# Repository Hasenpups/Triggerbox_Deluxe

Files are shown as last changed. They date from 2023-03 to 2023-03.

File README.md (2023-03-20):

Shield: [][cc-by-nc-sa]

This work is licensed under a
[Creative Commons Attribution-NonCommercial-ShareAlike 4.0 International License][cc-by-nc-sa].

[][cc-by-nc-sa]

[cc-by-nc-sa]: http://creativecommons.org/licenses/by-nc-sa/4.0/
[cc-by-nc-sa-image]: https://licensebuttons.net/l/by-nc-sa/4.0/88x31.png
[cc-by-nc-sa-shield]: https://img.shields.io/badge/License-CC%20BY--NC--SA%204.0-lightgrey.svg

## Donations / Spenden
If somebody wants to support me for upcoming projects :)  
- PayPal:  
- Amazon Giftcard: https://www.amazon.de/Amazon-Gutschein-per-E-Mail-Amazon/dp/B0054PDOV8 - stefan.riese@me.com

# Triggerbox Deluxe

It's a trigger device for multiple devices and input counter.
- Raspberry Pi Pico
- 24V power input
- 8 x optocoupler input
- 8 x high side switch 24V 500mA output
- optional Wifi interface instead of USB connection (ESP32C3)



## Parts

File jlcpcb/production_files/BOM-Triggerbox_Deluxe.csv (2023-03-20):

Comment | Designator | Footprint | LCSC
AO3401A | Q1,Q10,Q11,Q12,Q2,Q3,Q4,Q9 | SOT-23 | C15127
47µF | C2 | C_0805_2012Metric | C16780
10µF | C1 | C_0603_1608Metric | C19702
2N3904 | Q13,Q14,Q15,Q16,Q5,Q6,Q7,Q8 | SOT-23 | C20526
1K | R10,R11,R12,R25,R26,R27,R28,R29,R30,R31,R32,R5,R6,R7,R8,R9 | R_0603_1608Metric | C21190
220 | R65 | R_0603_1608Metric | C22962
3K3 | R13,R15,R17,R19,R33,R35,R37,R39,R41,R44,R47,R50,R53,R56,R59,R62 | R_0603_1608Metric | C22978
4.7K | R42,R43,R45,R46,R48,R49,R51,R52,R54,R55,R57,R58,R60,R61,R63,R64,R67 | R_0603_1608Metric | C23162
560 | R66 | R_0603_1608Metric | C23204
10K | R1,R14,R16,R18,R2,R20,R21,R22,R23,R24,R3,R34,R36,R38,R4,R40 | R_0603_1608Metric | C25804
EL3H7-G | U10,U11,U4,U5,U6,U7,U8,U9 | SOIC127P700X200-4N | C32565
100n | C10,C11,C4,C5,C6,C7,C8,C9 | C_0805_2012Metric_Pad1.18x1.45mm_HandSolder | C49678
AMS1117-3.3 | U1 | SOT-223-3_TabPin2 | C6186
LED | D1,D10,D11,D12,D13,D14,D15,D16,D17,D18,D19,D2,D3,D4,D5,D6,D7,D8,D9 | LED_0805_2012Metric | C84256
Conn_02x08_Odd_Even | J4 | PinHeader_2x08_P2.54mm_Vertical
Conn_02x03_Odd_Even | J3 | PinHeader_2x03_P2.54mm_Vertical
MountingHole | H1 | MountingHole_3.2mm_M3_DIN965_Pad
78TV | IC1 | TO-220-3_Horizontal_TabUp
MountingHole | H4 | MountingHole_3.2mm_M3_DIN965_Pad
MountingHole | H3 | MountingHole_3.2mm_M3_DIN965_Pad
C-EUC1206 | C3 | C_1206_3216Metric
Screw_Terminal_01x10 | J1 | TerminalBlock_Phoenix_MKDS-1,5-10-5.08_1x10_P5.08mm_Horizontal
Screw_Terminal_01x10 | J2 | TerminalBlock_Phoenix_MKDS-1,5-10-5.08_1x10_P5.08mm_Horizontal
MountingHole | H2 | MountingHole_3.2mm_M3_DIN965_Pad
C | C12 | C_1206_3216Metric_Pad1.33x1.80mm_HandSolder
ESP-01v090 | U3 | ESP-01
Conn_02x08_Odd_Even | J5 | PinHeader_2x08_P2.54mm_Vertical
Pico | U2 | RPi_Pico_SMD_TH
Jumper_2_Open | JP3 | PinHeader_1x02_P2.54mm_Vertical
Jumper_2_Open | JP2 | PinHeader_1x02_P2.54mm_Vertical
Jumper_2_Open | JP1 | PinHeader_1x02_P2.54mm_Vertical

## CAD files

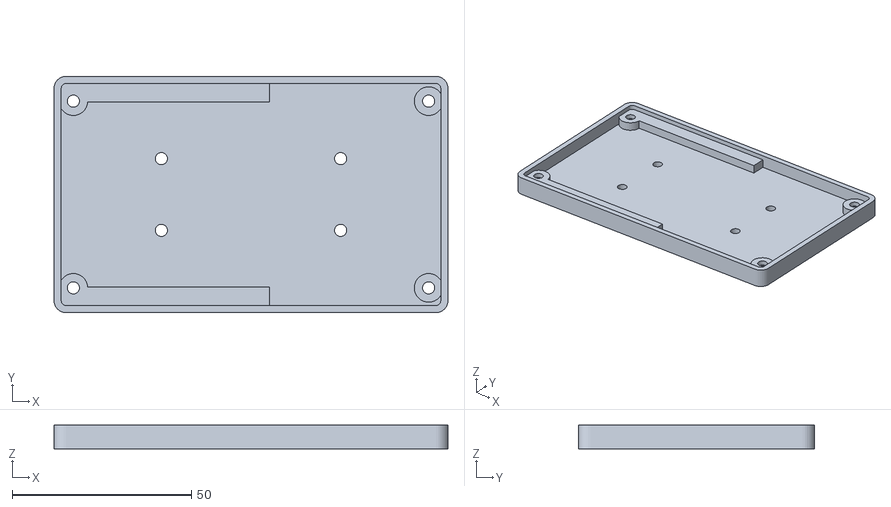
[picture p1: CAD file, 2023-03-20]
Housing/Triggerbox_Deluxe_Base.stl
109.9 x 65.9 x 6.60

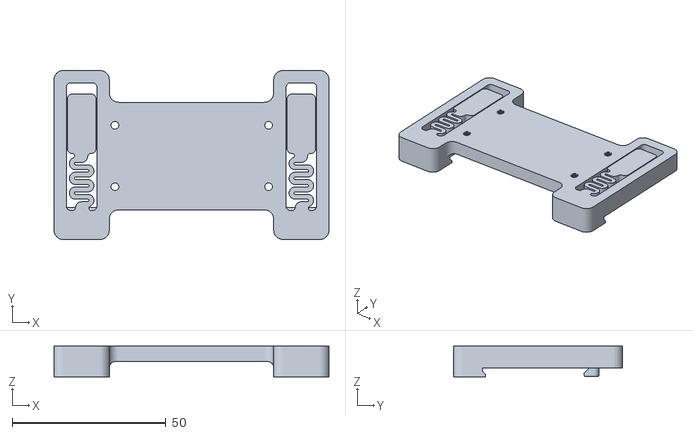
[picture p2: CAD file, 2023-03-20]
Housing/Triggerbox_Deluxe_Rail_Mount.stl
89.5 x 55.0 x 10.0

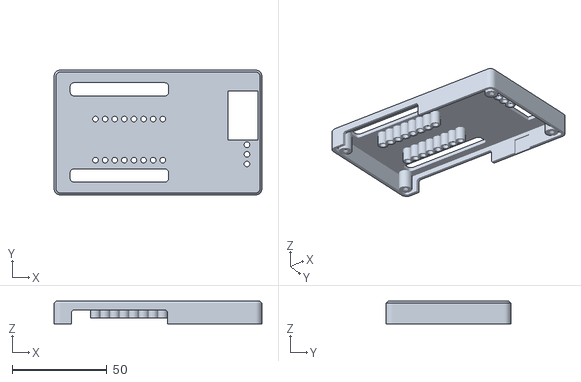
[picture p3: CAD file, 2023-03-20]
Housing/Triggerbox_Deluxe_Top.stl
109.9 x 65.9 x 12.0

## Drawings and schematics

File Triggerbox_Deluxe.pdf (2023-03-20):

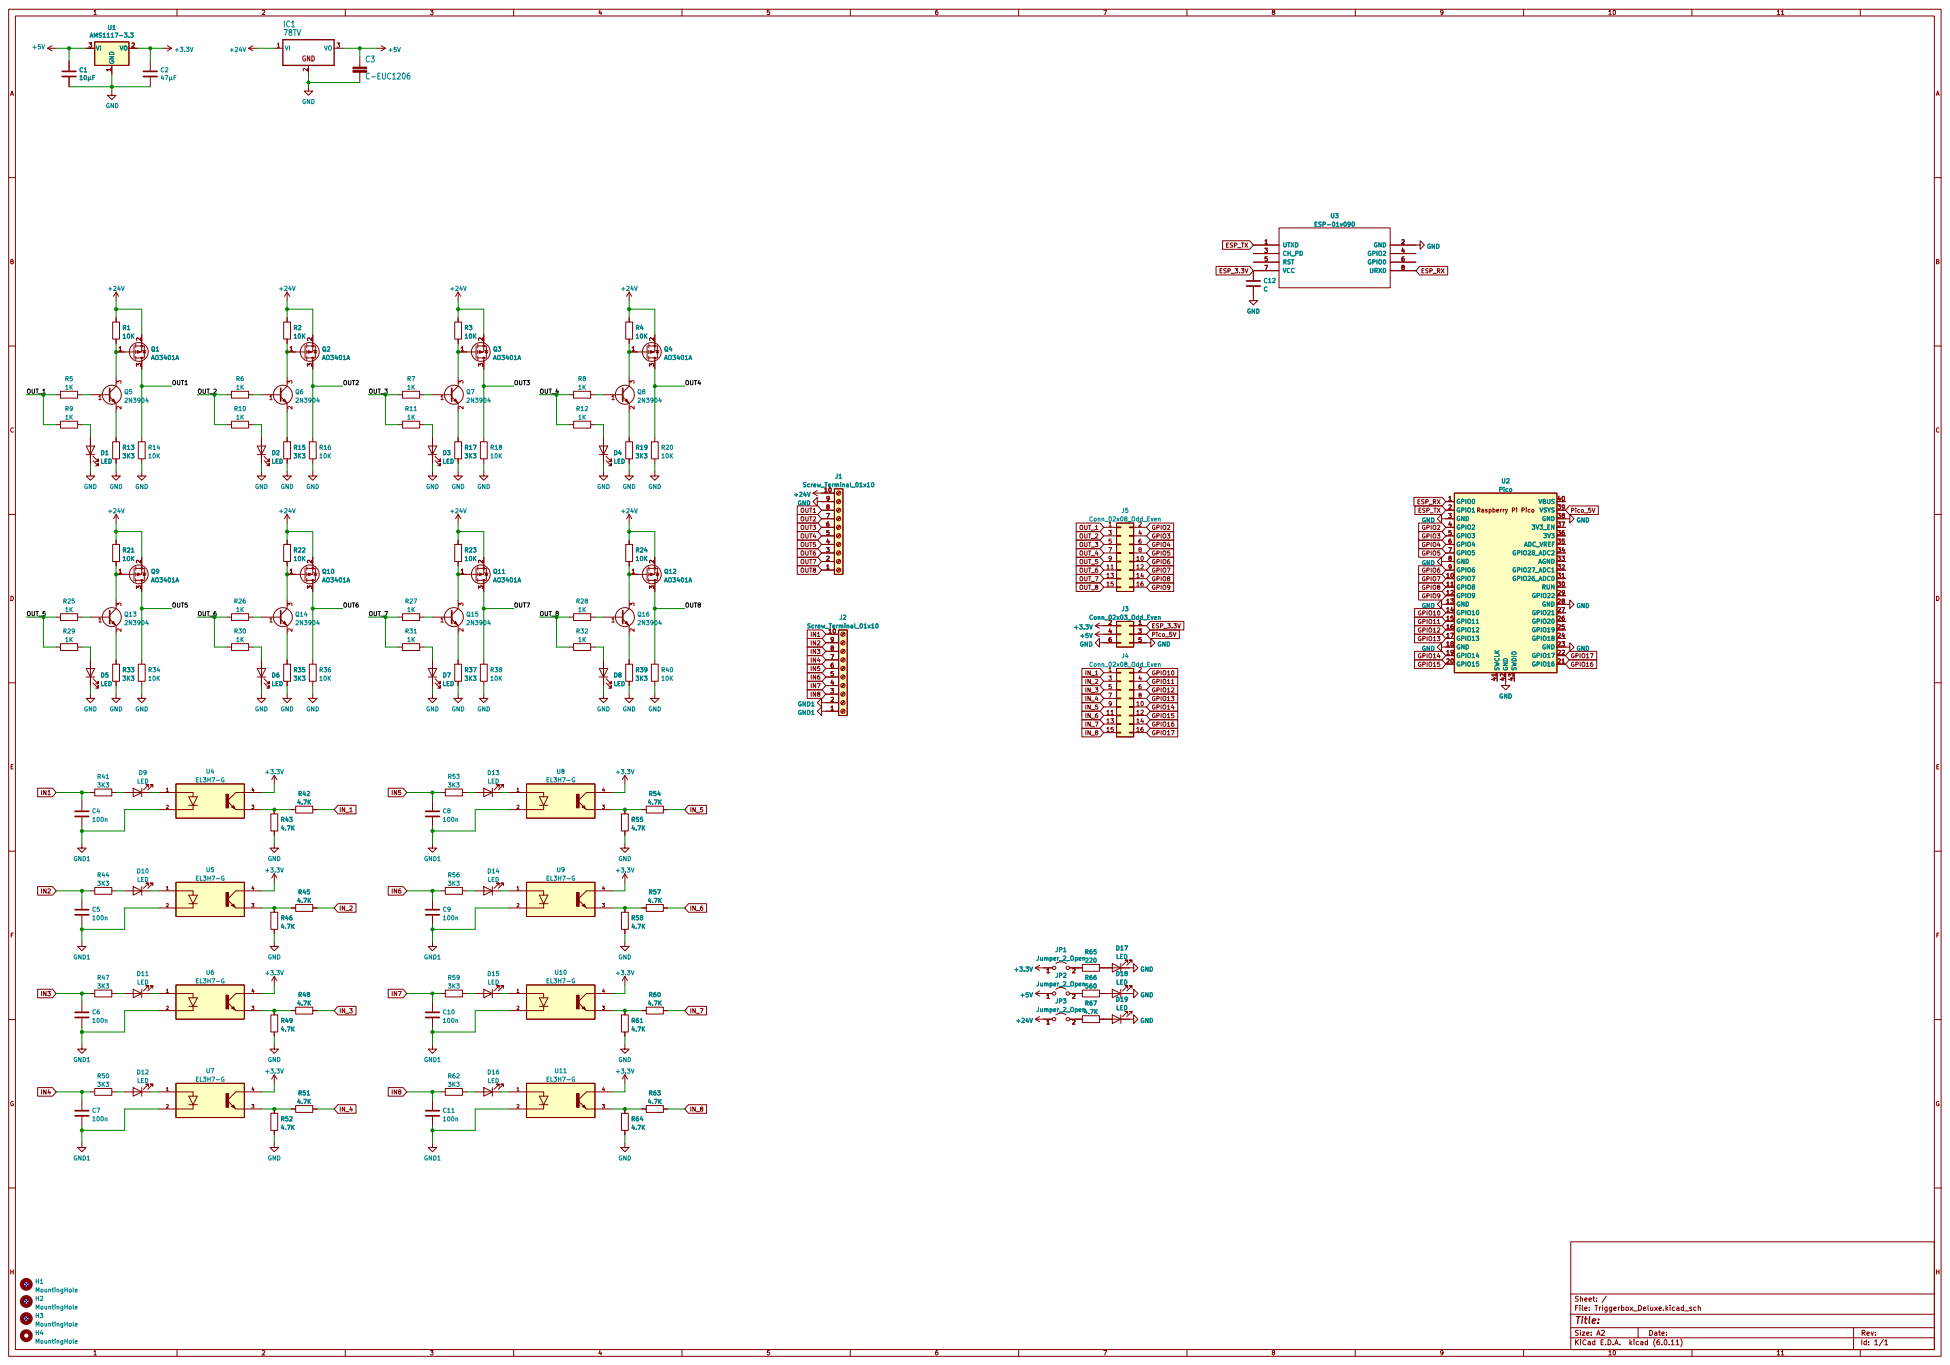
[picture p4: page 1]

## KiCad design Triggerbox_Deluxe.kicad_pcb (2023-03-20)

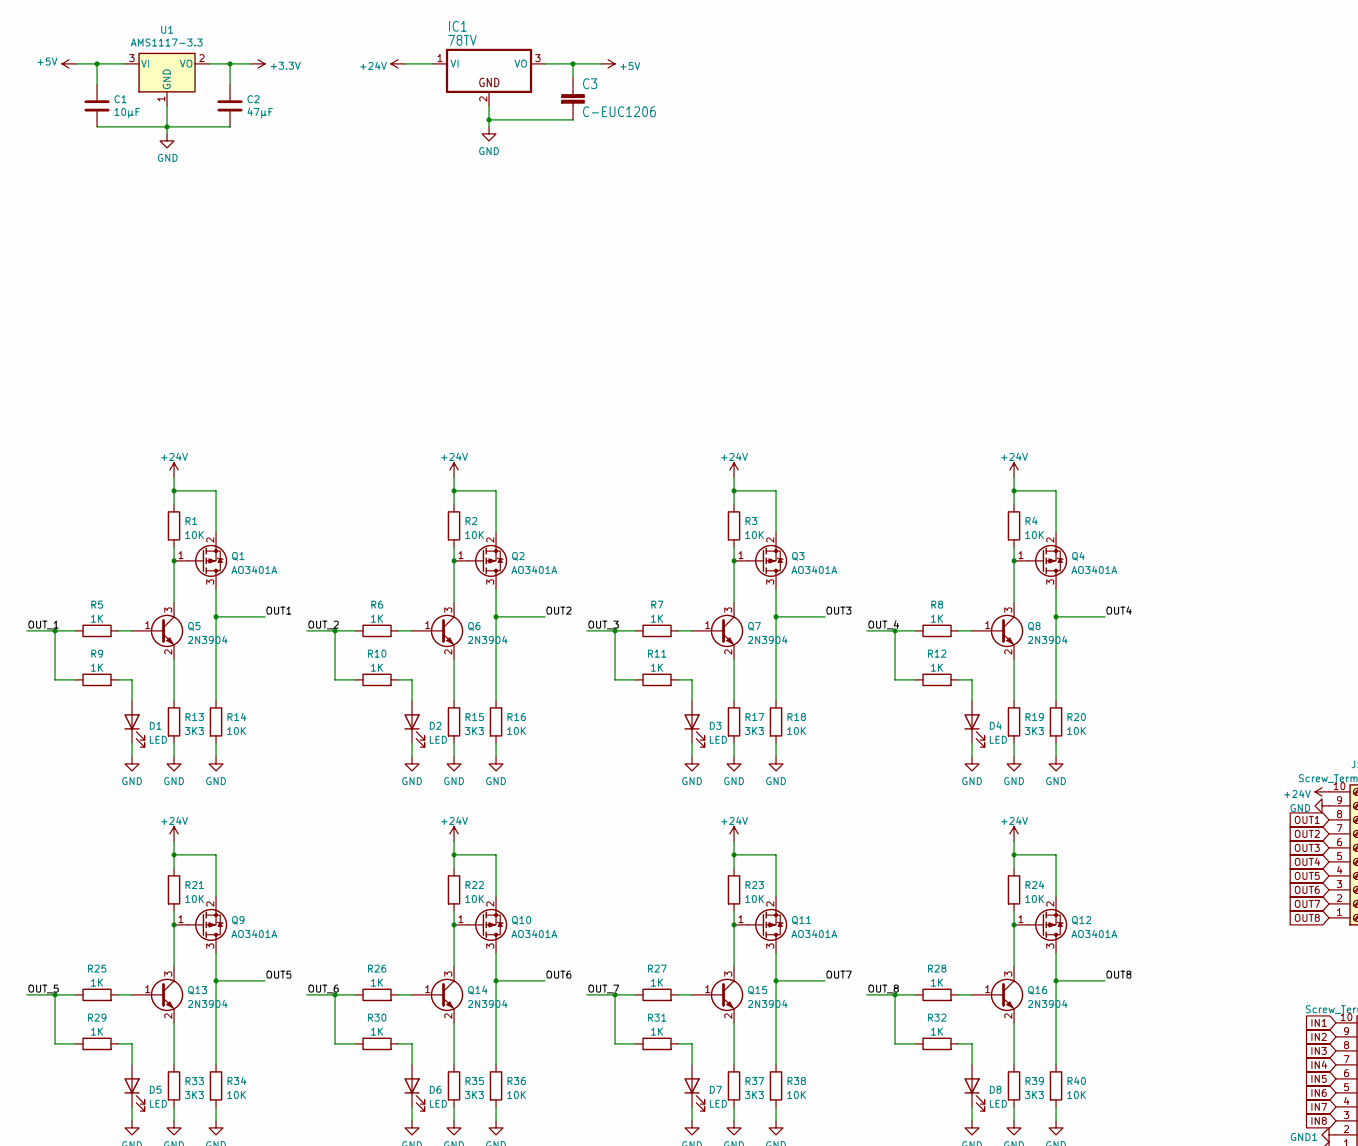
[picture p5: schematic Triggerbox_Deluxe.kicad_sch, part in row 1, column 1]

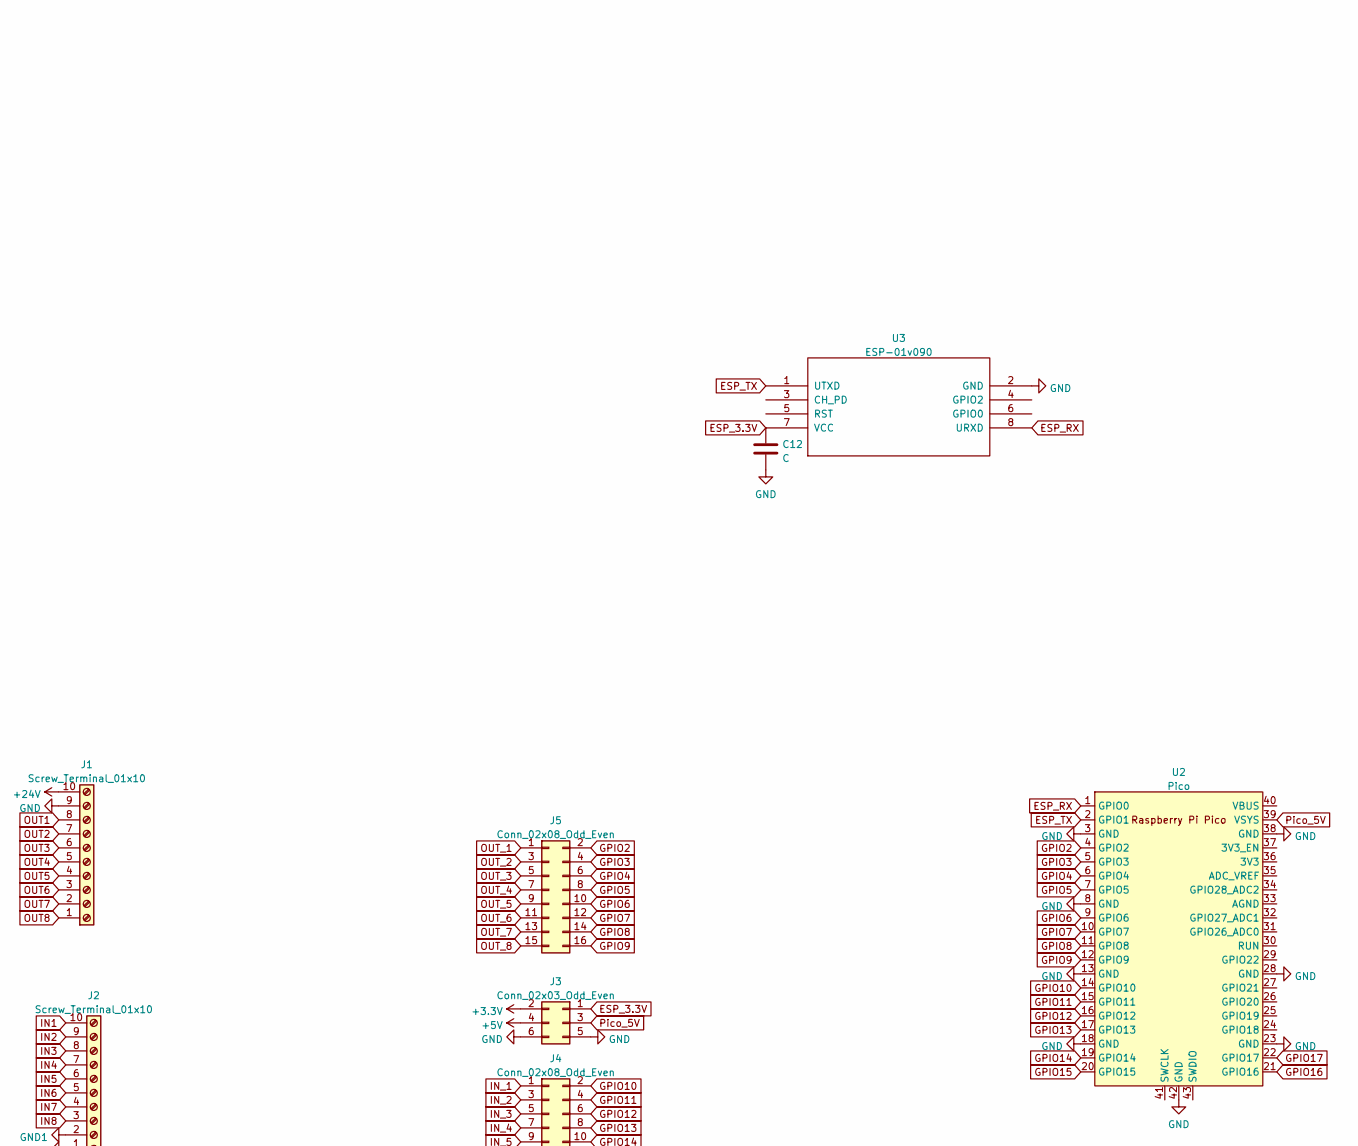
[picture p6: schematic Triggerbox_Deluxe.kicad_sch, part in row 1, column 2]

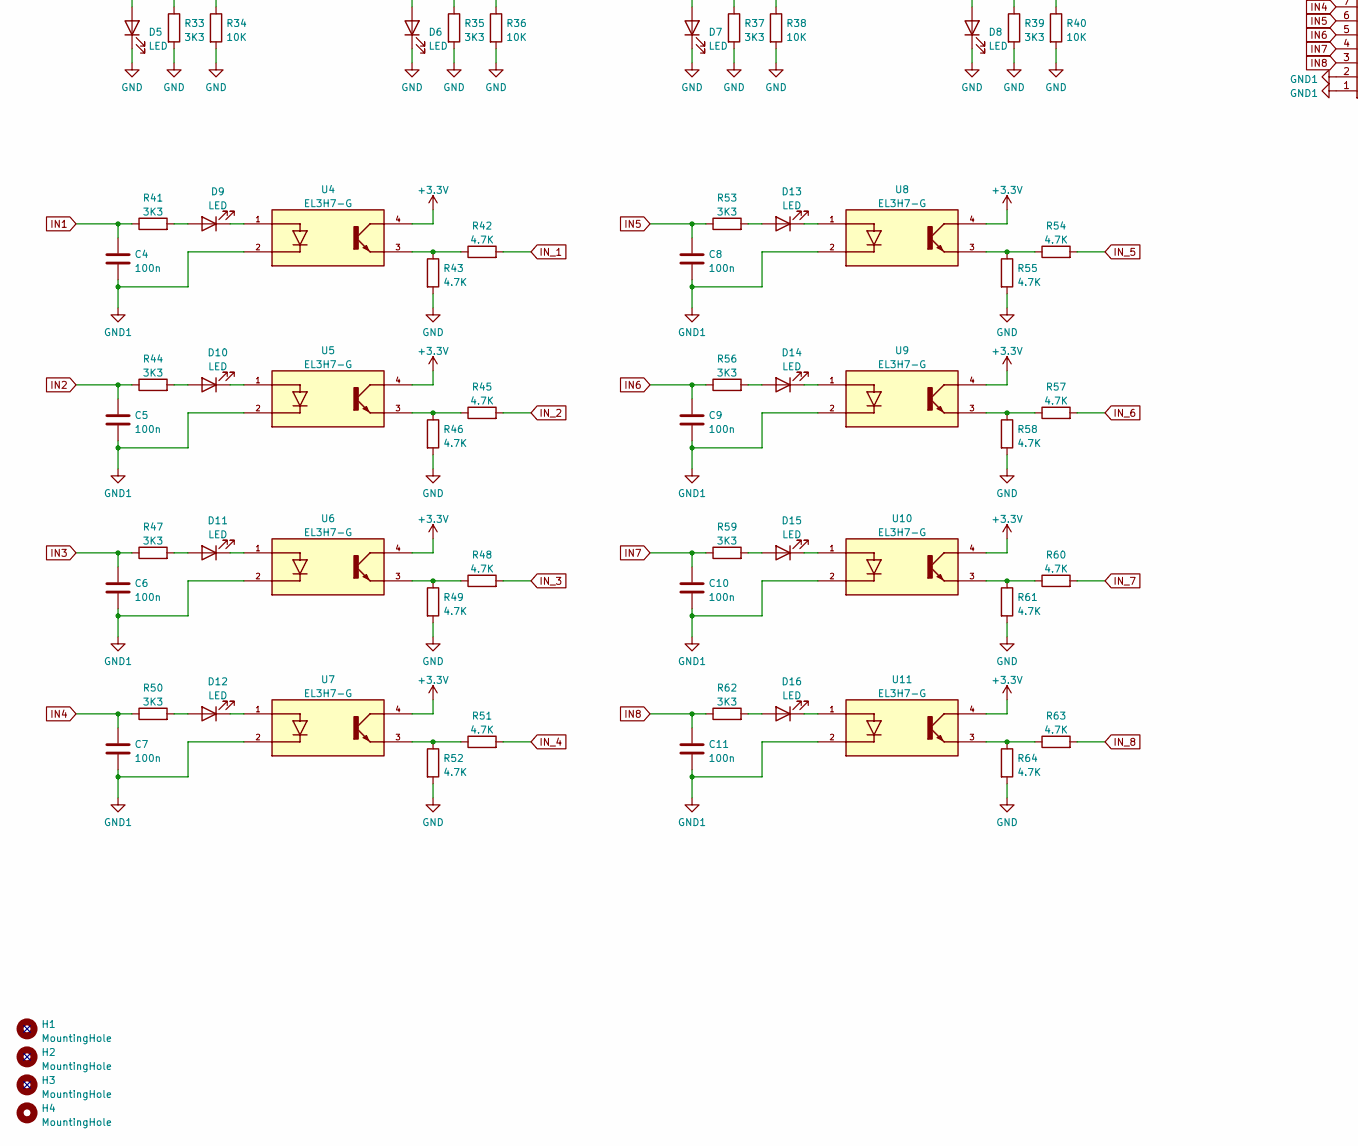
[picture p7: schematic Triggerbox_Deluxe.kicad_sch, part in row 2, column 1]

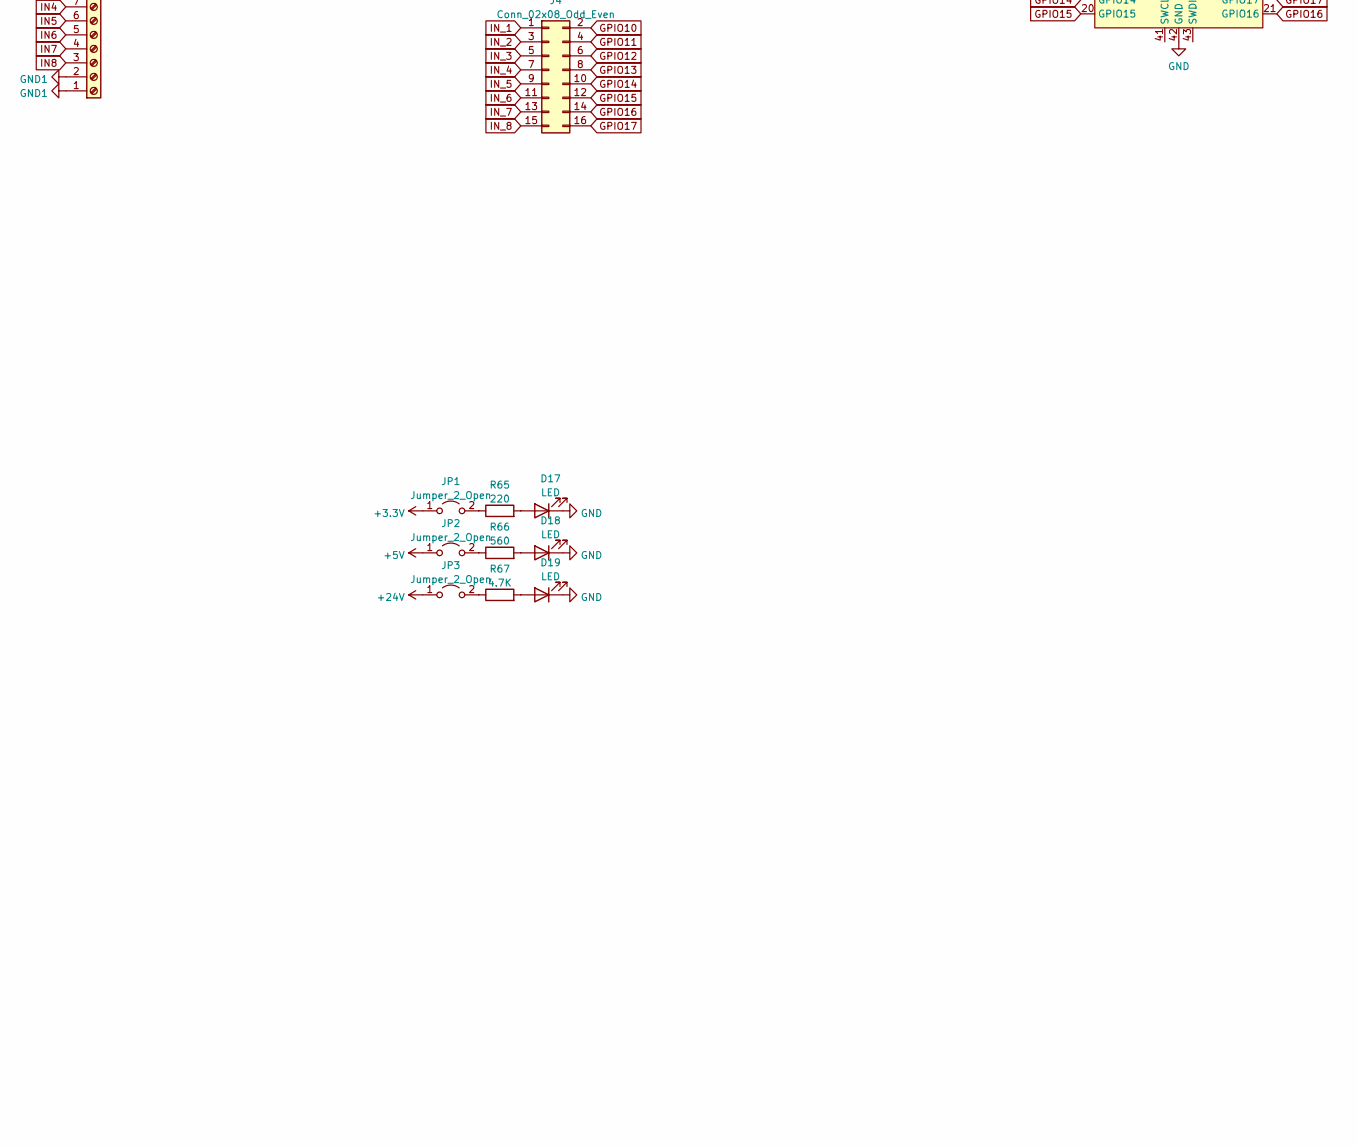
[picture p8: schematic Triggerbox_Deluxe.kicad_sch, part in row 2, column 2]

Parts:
C1: 10µF; C_0603_1608Metric; LCSC C19702
C2: 47µF; C_0805_2012Metric; LCSC C16780
C3: C-EUC1206; C_1206_3216Metric
C4, C5, C6, C7, C8, C9, C10, C11: 100n; C_0805_2012Metric_Pad1.18x1.45mm_HandSolder; LCSC C49678
C12: C; C_1206_3216Metric_Pad1.33x1.80mm_HandSolder
D1, D2, D3, D4, D5, D6, D7, D8, D9, D10, D11, D12, D13, D14, D15, D16, D17, D18, D19: LED; LED_0805_2012Metric; LCSC C84256
H1, H2, H3, H4: MountingHole; MountingHole_3.2mm_M3_DIN965_Pad
IC1: 78TV; TO-220-3_Horizontal_TabUp
J1, J2: Screw_Terminal_01x10; TerminalBlock_Phoenix_MKDS-1,5-10-5.08_1x10_P5.08mm_Horizon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
J3: Conn_02x03_Odd_Even; PinHeader_2x03_P2.54mm_Vertical
J4, J5: Conn_02x08_Odd_Even; PinHeader_2x08_P2.54mm_Vertical
JP1, JP2, JP3: Jumper_2_Open; PinHeader_1x02_P2.54mm_Vertical
Q1, Q2, Q3, Q4, Q9, Q10, Q11, Q12: AO3401A; SOT-23; LCSC C15127
Q5, Q6, Q7, Q8, Q13, Q14, Q15, Q16: 2N3904; SOT-23; LCSC C20526
R1, R2, R3, R4, R14, R16, R18, R20, R21, R22, R23, R24, R34, R36, R38, R40: 10K; R_0603_1608Metric; LCSC C25804
R5, R6, R7, R8, R9, R10, R11, R12, R25, R26, R27, R28, R29, R30, R31, R32: 1K; R_0603_1608Metric; LCSC C21190
R13, R15, R17, R19, R33, R35, R37, R39, R41, R44, R47, R50, R53, R56, R59, R62: 3K3; R_0603_1608Metric; LCSC C22978
R42, R43, R45, R46, R48, R49, R51, R52, R54, R55, R57, R58, R60, R61, R63, R64, R67: 4.7K; R_0603_1608Metric; LCSC C23162
R65: 220; R_0603_1608Metric; LCSC C22962
R66: 560; R_0603_1608Metric; LCSC C23204
U1: AMS1117-3.3; SOT-223-3_TabPin2; LCSC C6186
U2: Pico; RPi_Pico_SMD_TH
U3: ESP-01v090; ESP-01
U4, U5, U6, U7, U8, U9, U10, U11: EL3H7-G; SOIC127P700X200-4N; PARTREV 7; LCSC C32565

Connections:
+3.3V: C2.1, J3.2, JP1.1 (A), U1.2 (VO), U4.4, U5.4, U6.4, U7.4, U8.4, U9.4, U10.4, U11.4
+5V: C1.1, C3.1, IC1.3 (VO), J3.4, JP2.1 (A), U1.3 (VI)
+24V: IC1.1 (VI), J1.10, JP3.1 (A), Q1.2 (S), Q2.2 (S), Q3.2 (S), Q4.2 (S), Q9.2 (S), Q10.2 (S), Q11.2 (S), Q12.2 (S), R1.1, R2.1, R3.1, R4.1, R21.1, R22.1, R23.1, R24.1
ESP_3.3V: C12.1, J3.1, U3.7 (VCC)
ESP_RX: U2.1 (GPIO0), U3.8 (URXD)
ESP_TX: U2.2 (GPIO1), U3.1 (UTXD)
GND: C1.2, C2.2, C3.2, C12.2, D1.1 (K), D2.1 (K), D3.1 (K), D4.1 (K), D5.1 (K), D6.1 (K), D7.1 (K), D8.1 (K), D17.1 (K), D18.1 (K), D19.1 (K), IC1.2 (GND), J1.9, J3.5, J3.6, R13.2, R14.2, R15.2, R16.2, R17.2, R18.2, R19.2, R20.2, R33.2, R34.2, R35.2, R36.2, R37.2, R38.2, R39.2, R40.2, R43.2, R46.2, R49.2, R52.2, R55.2, R58.2, R61.2, R64.2, U1.1 (GND), U2.3 (GND), U2.8 (GND), U2.13 (GND), U2.18 (GND), U2.23 (GND), U2.28 (GND), U2.38 (GND), U2.42 (GND), U3.2 (GND)
GND1: C4.2, C5.2, C6.2, C7.2, C8.2, C9.2, C10.2, C11.2, J2.1, J2.2, U4.2, U5.2, U6.2, U7.2, U8.2, U9.2, U10.2, U11.2
GPIO2: J5.2, U2.4 (GPIO2)
GPIO3: J5.4, U2.5 (GPIO3)
GPIO4: J5.6, U2.6 (GPIO4)
GPIO5: J5.8, U2.7 (GPIO5)
GPIO6: J5.10, U2.9 (GPIO6)
GPIO7: J5.12, U2.10 (GPIO7)
GPIO8: J5.14, U2.11 (GPIO8)
GPIO9: J5.16, U2.12 (GPIO9)
GPIO10: J4.2, U2.14 (GPIO10)
GPIO11: J4.4, U2.15 (GPIO11)
GPIO12: J4.6, U2.16 (GPIO12)
GPIO13: J4.8, U2.17 (GPIO13)
GPIO14: J4.10, U2.19 (GPIO14)
GPIO15: J4.12, U2.20 (GPIO15)
GPIO16: J4.14, U2.21 (GPIO16)
GPIO17: J4.16, U2.22 (GPIO17)
IN1: C4.1, J2.10, R41.1
IN2: C5.1, J2.9, R44.1
IN3: C6.1, J2.8, R47.1
IN4: C7.1, J2.7, R50.1
IN5: C8.1, J2.6, R53.1
IN6: C9.1, J2.5, R56.1
IN7: C10.1, J2.4, R59.1
IN8: C11.1, J2.3, R62.1
IN_1: J4.1, R42.2
IN_2: J4.3, R45.2
IN_3: J4.5, R48.2
IN_4: J4.7, R51.2
IN_5: J4.9, R54.2
IN_6: J4.11, R57.2
IN_7: J4.13, R60.2
IN_8: J4.15, R63.2
unnamed: D1.2 (A), R9.2
unnamed: D2.2 (A), R10.2
unnamed: D3.2 (A), R11.2
unnamed: D4.2 (A), R12.2
unnamed: D5.2 (A), R29.2
unnamed: D6.2 (A), R30.2
unnamed: D7.2 (A), R31.2
unnamed: D8.2 (A), R32.2
unnamed: D9.1 (K), U4.1
unnamed: D9.2 (A), R41.2
unnamed: D10.1 (K), U5.1
unnamed: D10.2 (A), R44.2
unnamed: D11.1 (K), U6.1
unnamed: D11.2 (A), R47.2
unnamed: D12.1 (K), U7.1
unnamed: D12.2 (A), R50.2
unnamed: D13.1 (K), U8.1
unnamed: D13.2 (A), R53.2
unnamed: D14.1 (K), U9.1
unnamed: D14.2 (A), R56.2
unnamed: D15.1 (K), U10.1
unnamed: D15.2 (A), R59.2
unnamed: D16.1 (K), U11.1
unnamed: D16.2 (A), R62.2
unnamed: D17.2 (A), R65.2
unnamed: D18.2 (A), R66.2
unnamed: D19.2 (A), R67.2
unnamed: JP1.2 (B), R65.1
unnamed: JP2.2 (B), R66.1
unnamed: JP3.2 (B), R67.1
unnamed: Q1.1 (G), Q5.3 (C), R1.2
unnamed: Q2.1 (G), Q6.3 (C), R2.2
unnamed: Q3.1 (G), Q7.3 (C), R3.2
unnamed: Q4.1 (G), Q8.3 (C), R4.2
unnamed: Q5.1 (B), R5.2
unnamed: Q5.2 (E), R13.1
unnamed: Q6.1 (B), R6.2
unnamed: Q6.2 (E), R15.1
unnamed: Q7.1 (B), R7.2
unnamed: Q7.2 (E), R17.1
unnamed: Q8.1 (B), R8.2
unnamed: Q8.2 (E), R19.1
unnamed: Q10.1 (G), Q14.3 (C), R22.2
unnamed: Q11.1 (G), Q15.3 (C), R23.2
unnamed: Q12.1 (G), Q16.3 (C), R24.2
unnamed: Q13.1 (B), R25.2
unnamed: Q13.2 (E), R33.1
unnamed: Q9.1 (G), Q13.3 (C), R21.2
unnamed: Q14.1 (B), R26.2
unnamed: Q14.2 (E), R35.1
unnamed: Q15.1 (B), R27.2
unnamed: Q15.2 (E), R37.1
unnamed: Q16.1 (B), R28.2
unnamed: Q16.2 (E), R39.1
unnamed: R42.1, R43.1, U4.3
unnamed: R45.1, R46.1, U5.3
unnamed: R48.1, R49.1, U6.3
unnamed: R51.1, R52.1, U7.3
unnamed: R54.1, R55.1, U8.3
unnamed: R57.1, R58.1, U9.3
unnamed: R60.1, R61.1, U10.3
unnamed: R63.1, R64.1, U11.3
OUT1: J1.8, Q1.3 (D), R14.1
OUT2: J1.7, Q2.3 (D), R16.1
OUT3: J1.6, Q3.3 (D), R18.1
OUT4: J1.5, Q4.3 (D), R20.1
OUT5: J1.4, Q9.3 (D), R34.1
OUT6: J1.3, Q10.3 (D), R36.1
OUT7: J1.2, Q11.3 (D), R38.1
OUT8: J1.1, Q12.3 (D), R40.1
OUT_1: J5.1, R5.1, R9.1
OUT_2: J5.3, R6.1, R10.1
OUT_3: J5.5, R7.1, R11.1
OUT_4: J5.7, R8.1, R12.1
OUT_5: J5.9, R25.1, R29.1
OUT_6: J5.11, R26.1, R30.1
OUT_7: J5.13, R27.1, R31.1
OUT_8: J5.15, R28.1, R32.1
Pico_5V: J3.3, U2.39 (VSYS)

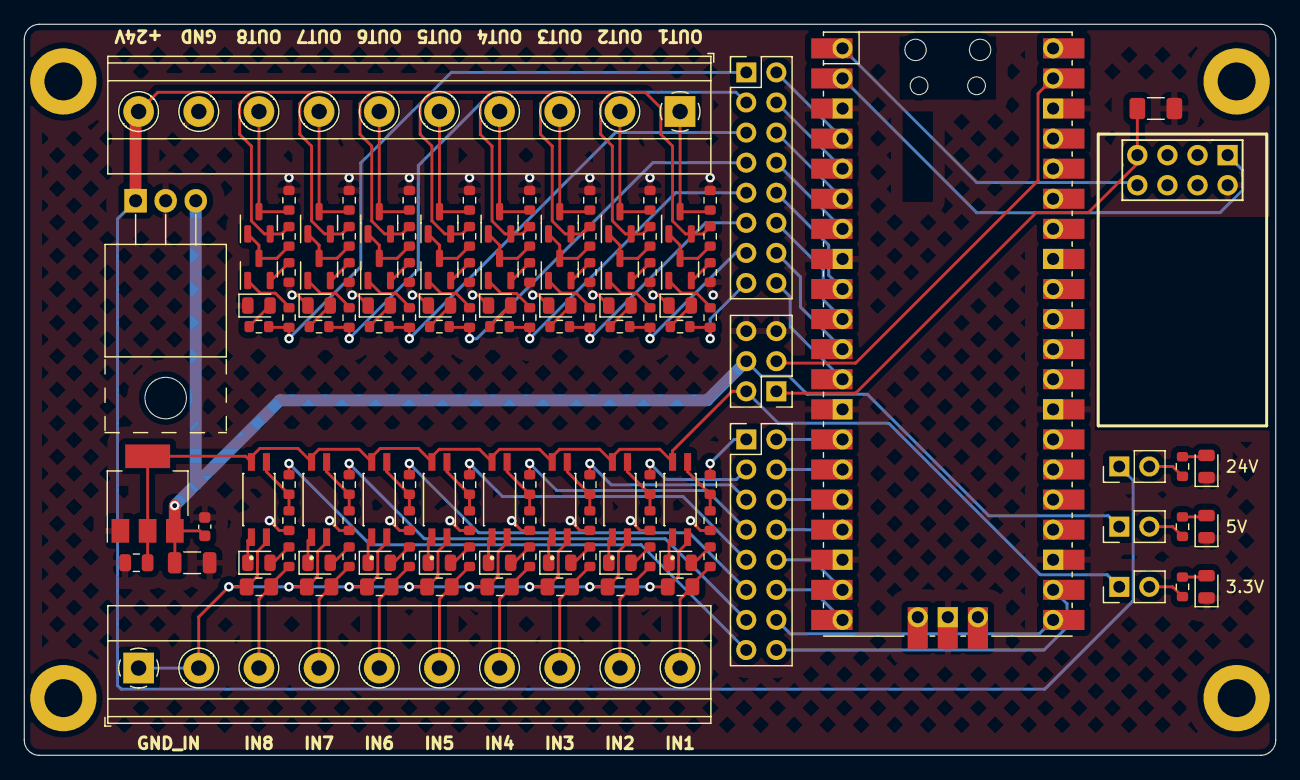
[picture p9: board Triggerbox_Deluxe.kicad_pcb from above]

Board: 2 copper layers, 105.7 x 61.7 mm, 138 parts (0 on the bottom side), 119 nets.

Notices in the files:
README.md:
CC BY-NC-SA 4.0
